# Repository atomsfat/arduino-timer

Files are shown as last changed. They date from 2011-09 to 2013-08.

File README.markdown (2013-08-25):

Arduino timer
=============
This is a configurable timer using arduino, rtc (DS1307) and a lcd display
* For debian and ubuntu install avr tools:

```bash
apt-get install avrdude binutils-avr gcc-avr avr-libc gdb-avr
```
* For fedora
```bash
yum install uisp avr-libc avr-gcc-c++ avr-gcc avr-binutils avr-libc avr-gdb avrdude 
```

* Install eclipse-cpp
* Configure the project:
File>Project>Makefile with existing source
* Install arduino-022
* Change the following in the Makefile:
  * ARDUINO_PATH
  * AVRDUDE_PORT
  * AVR_TOOLS_PATH

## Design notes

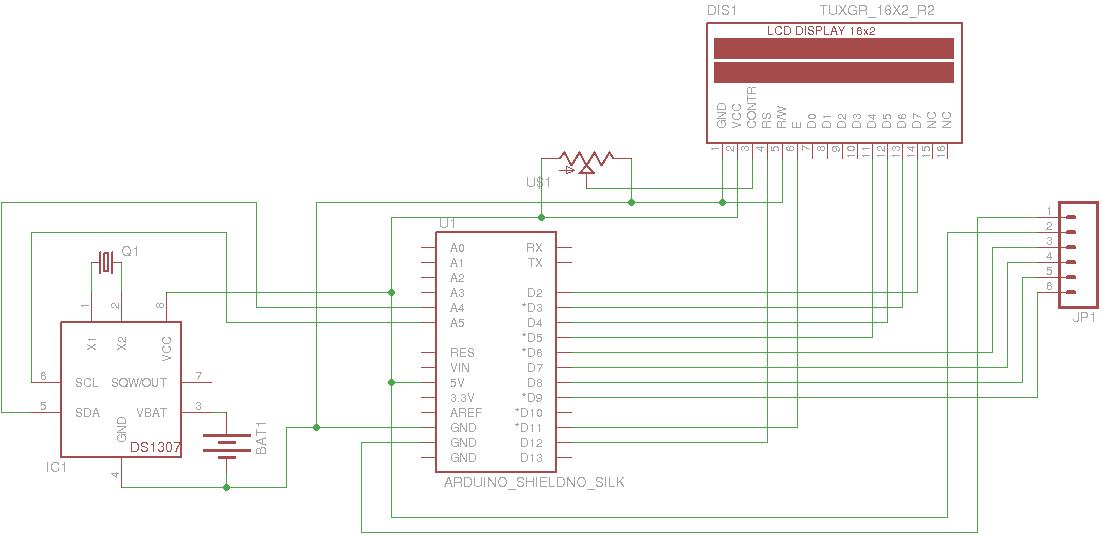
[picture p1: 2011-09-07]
media/schema.png

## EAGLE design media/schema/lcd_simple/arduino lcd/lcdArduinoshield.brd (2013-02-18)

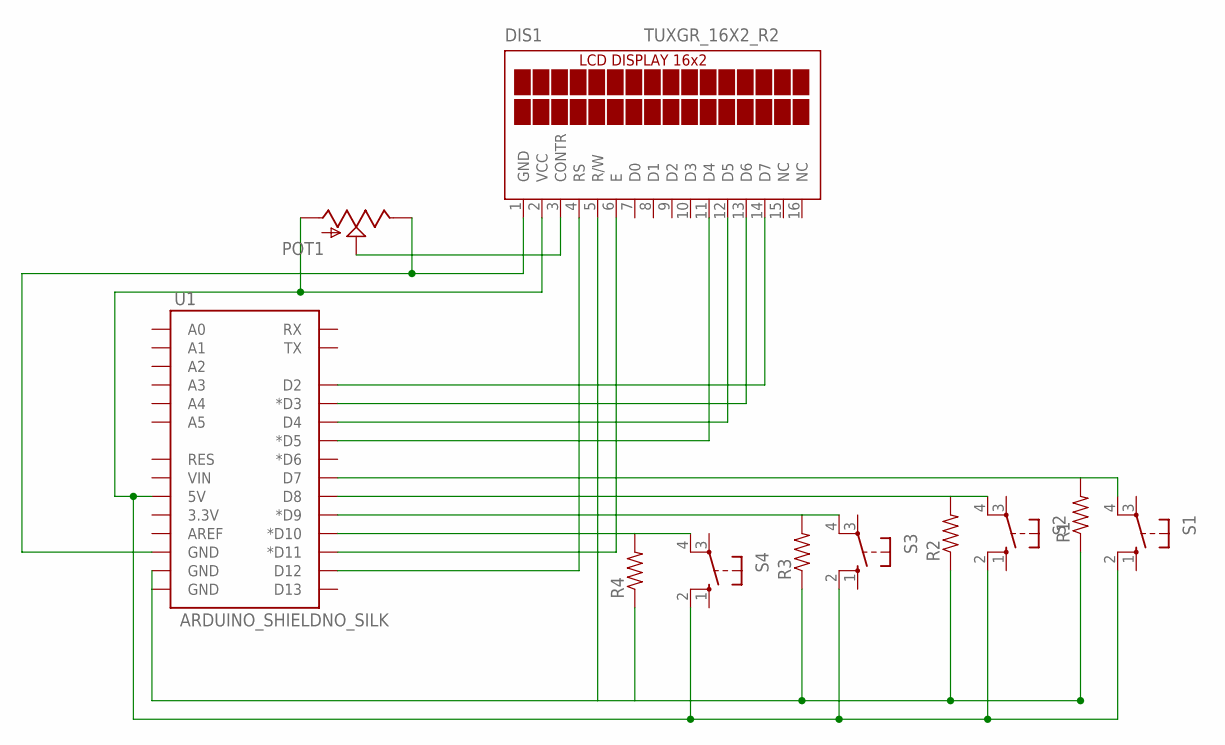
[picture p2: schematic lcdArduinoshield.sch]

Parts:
DIS1: TUXGR_16X2_R2
POT1: POT100K_3362U; 3362U
R1, R2, R3, R4: RESISTORPTH-1/4W; AXIAL-0.4
S1, S2, S3, S4: 10-XX; B3F-10XX
U1: ARDUINO_SHIELDNO_SILK; DUEMILANOVE_VIAS

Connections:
+5V: DIS1.2 (VCC), POT1.P$3 (A), S1.2 (S1), S2.2 (S1), S3.2 (S1), S4.2 (S1), U1.5V
GND: DIS1.1 (GND), POT1.P$1 (E), U1.GND@2 (GND)
GND1: DIS1.5 (R/W), R1.P$1 (1), R2.P$1 (1), R3.P$1 (1), R4.P$1 (1), U1.GND@0 (GND), U1.GND@1 (GND)
unnamed: DIS1.14 (D7), U1.D2
unnamed: DIS1.13 (D6), U1.D3 (*D3)
unnamed: DIS1.12 (D5), U1.D4
unnamed: DIS1.11 (D4), U1.D5 (*D5)
unnamed: DIS1.6 (E), U1.D11 (*D11)
unnamed: R4.P$2 (2), S4.4 (P1), U1.D10 (*D10)
unnamed: DIS1.4 (RS), U1.D12
unnamed: R3.P$2 (2), S3.4 (P1), U1.D9 (*D9)
unnamed: R2.P$2 (2), S2.4 (P1), U1.D8
unnamed: R1.P$2 (2), S1.4 (P1), U1.D7
POTDIV: DIS1.3 (CONTR), POT1.P$2 (S)

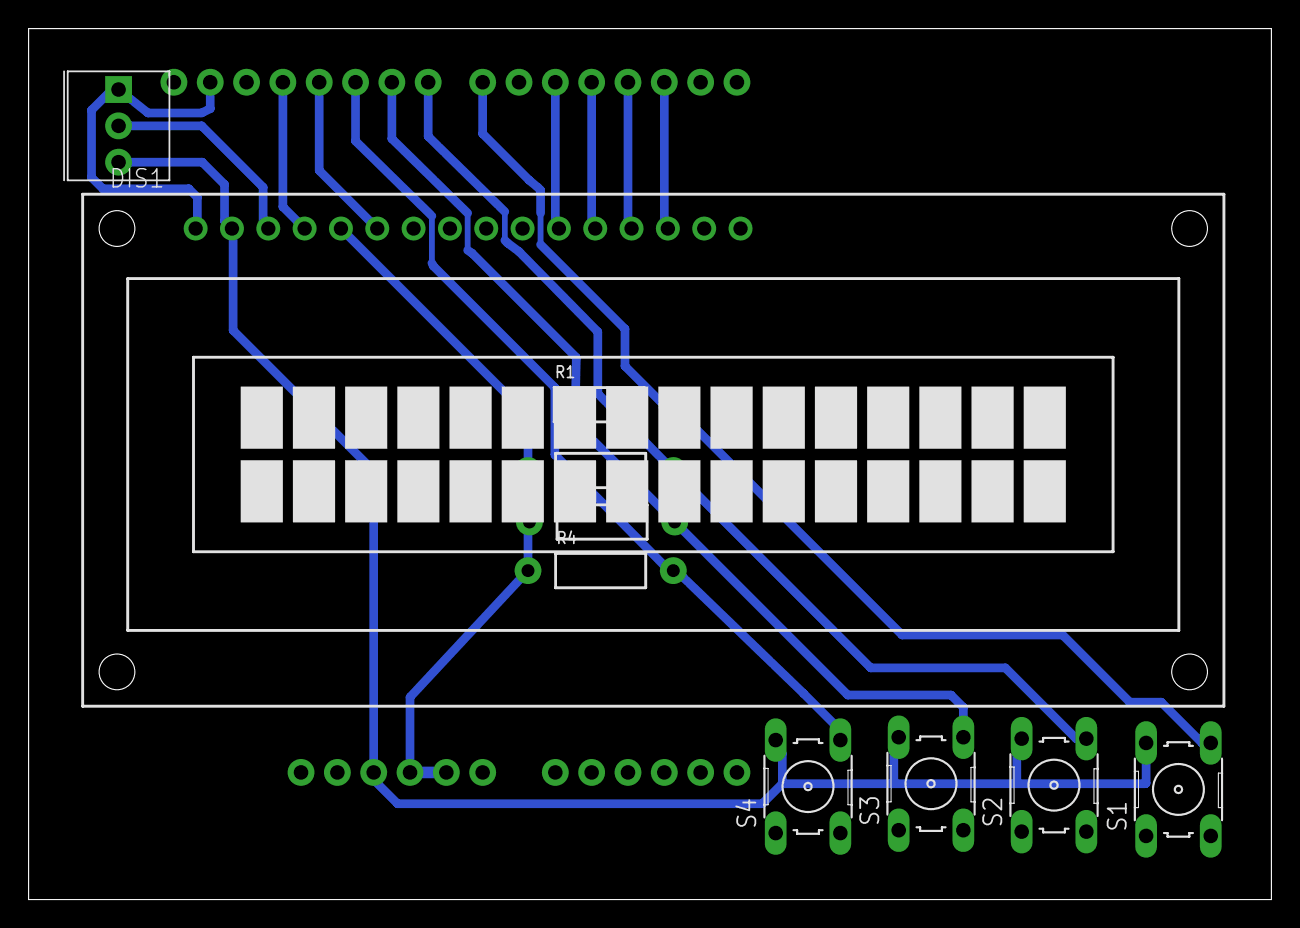
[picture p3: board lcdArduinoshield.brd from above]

Board: 2 copper layers, 86.9 x 60.9 mm, 11 parts (0 on the bottom side), 14 nets.

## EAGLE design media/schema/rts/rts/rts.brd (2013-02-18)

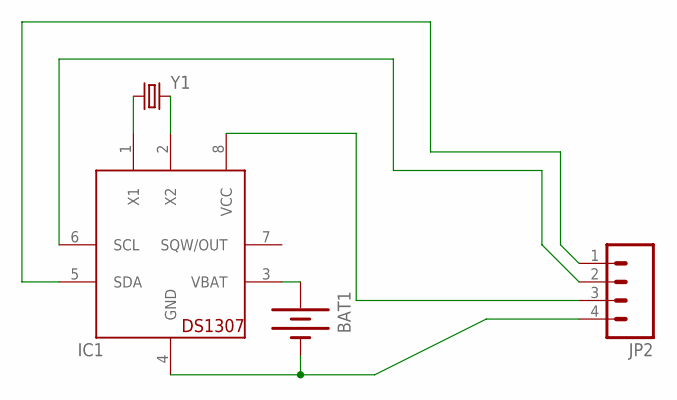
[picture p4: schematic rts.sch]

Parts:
BAT1: BATTERYFOB; BATTERY_20MM_PTH_COMPACT
IC1: DS1307; DIL08
JP2: M04LONGPADS; 1X04_LONGPADS
Y1: CRYSTALTC38H; TC38H

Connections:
GND: BAT1.2 (-), IC1.4 (GND), JP2.4
unnamed: IC1.2 (X2), Y1.2
unnamed: IC1.1 (X1), Y1.1
unnamed: IC1.8 (VCC), JP2.3
unnamed: BAT1.1 (+), IC1.3 (VBAT)
unnamed: IC1.5 (SDA), JP2.1
unnamed: IC1.6 (SCL), JP2.2

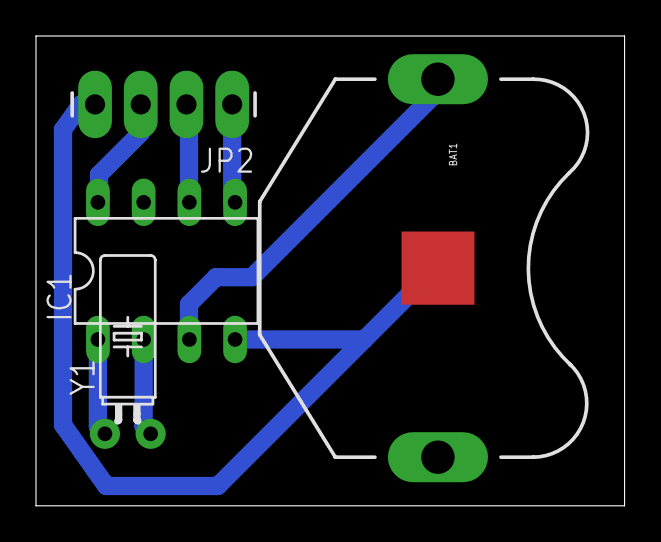
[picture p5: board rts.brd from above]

Board: 2 copper layers, 32.7 x 26.1 mm, 4 parts (0 on the bottom side), 7 nets.

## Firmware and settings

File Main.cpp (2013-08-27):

#if defined(ARDUINO) && ARDUINO >= 100
#include "Arduino.h"
#else
#include "WProgram.h"
#endif

#include "LiquidCrystal.h"
#include <Wire.h>

#include <stdlib.h>
#include <RTClib.h>

#include "Controller.h"
#include "Model.h"

#include "Servo.h"

// prototypes
void * operator new(size_t size);
void operator delete(void * ptr);
//enable inherance
__extension__ typedef int __guard __attribute__((mode (__DI__)));

extern "C" int __cxa_guard_acquire(__guard *);
extern "C" void __cxa_guard_release(__guard *);
extern "C" void __cxa_guard_abort(__guard *);

//normal
void setup();
void loop();

//this enable new operator
void * operator new(size_t size) {
	return malloc(size);
}
//this enable delete operator
void operator delete(void * ptr) {
	free(ptr);
}

int __cxa_guard_acquire(__guard *g) {
	return !*(char *) (g);
}
;
void __cxa_guard_release(__guard *g) {
	*(char *) g = 1;
}
;
void __cxa_guard_abort(__guard *) {
}
;

extern "C" void __cxa_pure_virtual() {
	cli();
	for (;;)
		;
}

//Here my program start
Servo myservo;
// variables will change:
int minServo = 5; //
int maxServo = 175;

LiquidCrystal lcd(12, 11, 5, 4, 3, 2);

Model* model = new Model();
Controller controller(model);

char message[40] = "";

// constants won't change. They're used here to
// set pin numbers:
const int buttonUp = 8;
const int buttonDown = 9;

const int buttonOk = 7;
const int buttonCancel = 10;

RTC_DS1307 RTC;
DateTime current;

void setup() {

	// initialize the pushbutton as input
	pinMode(13, OUTPUT);
	digitalWrite(13, HIGH);

	pinMode(buttonDown, INPUT);
	pinMode(buttonUp, INPUT);
	pinMode(buttonOk, INPUT);
	pinMode(buttonCancel, INPUT);

	Wire.begin();
	RTC.begin();
	// configure display
	lcd.begin(1, 2);

	myservo.attach(6); //set servo to pin 10


	uint8_t buffer[8];
	RTC.readMemory(0, buffer, 8);

	for (int i = 0; i < 2; i++) {

		int offset = i * 4;

		model->programs[i].hourPG1 = buffer[offset];
		model->programs[i].minutePG1 = buffer[offset + 1];
		model->programs[i].minutesOnPG1 = buffer[offset + 2];
		model->programs[i].dayPG1 = buffer[offset + 3];

		if (model->programs[i].hourPG1 > 24 || model->programs[i].minutePG1
				> 60) {
			model->programs[i].hourPG1 = 0;
			model->programs[i].minutePG1 = 0;
			model->programs[i].minutesOnPG1 = 0;

		}
		if (model->programs[i].dayPG1 > 127) {
			model->programs[i].dayPG1 = 0;
		}
	}

}

void loop()

{

	uint8_t pg1[8];

	for (int i = 0; i < 2; i++) {

		int offset = i * 4;
		pg1[0 + offset] = model->programs[i].hourPG1;
		pg1[1 + offset] = model->programs[i].minutePG1;
		pg1[2 + offset] = model->programs[i].minutesOnPG1;
		pg1[3 + offset] = model->programs[i].dayPG1;

	}

	RTC.writeMemory(0, pg1, 8);

	current = RTC.now();

	model->current = current.unixtime();

	// read the state of the pushbutton
	if (digitalRead(buttonDown) == 1) {
		controller.pressDown();
	} else if (digitalRead(buttonUp) == 1) {
		controller.pressUp();
	} else if (digitalRead(buttonOk) == 1) {
		controller.pressOk();
	} else if (digitalRead(buttonCancel) == 1) {
		controller.pressCancel();
	}

	if (model->boilerOn) {
		myservo.write(maxServo);
	} else {
		myservo.write(minServo);
	}

	int dow = current.dayOfWeek();

	for (int i = 0; i < 2; i++) {
		if ( model->programs[i].hourPG1 > 0 &&  model->programs[i].minutePG1 > 0 &&  model->boilerOn
				== false) {
			DateTime dt0(current.year(), current.month(), current.day(),
					 model->programs[i].hourPG1,  model->programs[i].minutePG1, 0);

			int tD =  model->programs[i].dayPG1 & 1; //Domingo
			int tL =  model->programs[i].dayPG1 & 2;
			int tM =  model->programs[i].dayPG1 & 4;
			int tMi = model->programs[i].dayPG1 & 8;
			int tJ =  model->programs[i].dayPG1 & 16;
			int tV =  model->programs[i].dayPG1 & 32;
			int tS =  model->programs[i].dayPG1 & 64;

			if (dow == 0) {
				if (tD == 1) {
					model->whenItStarted = dt0.unixtime();
					model->whenToturnOff = model->whenItStarted
							+ (model->programs[i].minutesOnPG1 * 60);
				}
			} else if (dow == 1) { //lunes
				if (tL == 2) {
					model->whenItStarted = dt0.unixtime();
					model->whenToturnOff = model->whenItStarted
							+ (model->programs[i].minutesOnPG1 * 60);
				}

			} else if (dow == 2) {
				if (tM == 4) {
					model->whenItStarted = dt0.unixtime();
					model->whenToturnOff = model->whenItStarted
							+ (model->programs[i].minutesOnPG1 * 60);
				}

			} else if (dow == 3) {
				if (tMi == 8) {
					model->whenItStarted = dt0.unixtime();
					model->whenToturnOff = model->whenItStarted
							+ (model->programs[i].minutesOnPG1 * 60);
				}

			} else if (dow == 4) {
				if (tJ == 16) {
					model->whenItStarted = dt0.unixtime();
					model->whenToturnOff = model->whenItStarted
							+ (model->programs[i].minutesOnPG1 * 60);
				}

			} else if (dow == 5) {
				if (tV == 32) {
					model->whenItStarted = dt0.unixtime();
					model->whenToturnOff = model->whenItStarted
							+ (model->programs[i].minutesOnPG1 * 60);
				}
			} else if (dow == 6) {
				if (tS == 64) {
					model->whenItStarted = dt0.unixtime();
					model->whenToturnOff = model->whenItStarted
							+ (model->programs[i].minutesOnPG1 * 60);
				}
			}
		}
	}

	if (model->current > model->whenItStarted && model->current
			< model->whenToturnOff) {
		model->boilerOn = true;
	} else {
		model->boilerOn = false;
	}

	controller.display(message);

	//  lcd.clear();
	lcd.setCursor(0, 0);

	for (int i = 0; i < strlen(message); i++) {

		if ((i + 1) % 17 == 0) {
			lcd.setCursor(0, 1);
		}
		lcd.print(message[i]);

	}

	if (strlen(message) <= 17) {
		lcd.setCursor(0, 1);

		//lcd.print(dt7.year(), DEC);
		//lcd.print('/');
		// lcd.print(dt7.month(), DEC);
		// lcd.print('/');
		// lcd.print(dt7.day(), DEC);
		// lcd.print(' ');

		//		lcd.print(dow, DEC);
		//
		//		lcd.print(' ');


		lcd.print("    ");
		lcd.print(current.hour(), DEC);
		lcd.print(':');
		lcd.print(current.minute(), DEC);
		lcd.print(':');
		lcd.print(current.second(), DEC);
		lcd.print("    ");

	}

	delay(200);

}

int main(void) {
	init();

	setup();

	for (;;)
		loop();

	return 0;
}

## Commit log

2011-09-07 added schema
    [lcdArduinoshield.brd, lcdArduinoshield.sch, timer_lcd.fz]
2011-09-24 removed Makefile because it contains current user settings
2011-09-25 servo library
2011-09-25 added servo library to makefile
2011-10-05 funciona el despliegue de cuanto tiempo esta encendido
2013-02-18 added new schemas
    [Arduino_S3v3_R2.brd, Arduino_S3v3_R2.sch, Arduino_S3v3_R2_ft2.brd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]
2013-02-18 correcting files
    [Arduino_S3v3_R2.brd, Arduino_S3v3_R2.sch, Arduino_S3v3_R2_ft2.brd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]
2013-02-18 change cancel button because in pcb is changed
2013-03-21 adding servo
2013-04-01 trying support for arduino 1.0
2013-08-11 adding validation to avoid overflow
    [Main.cpp]
2013-08-11 adding new command to handle programing timer
2013-08-26 solving issues with memory eeprom now it works with ram from ds1307
    [Main.cpp]

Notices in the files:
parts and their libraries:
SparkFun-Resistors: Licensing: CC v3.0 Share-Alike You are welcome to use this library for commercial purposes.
